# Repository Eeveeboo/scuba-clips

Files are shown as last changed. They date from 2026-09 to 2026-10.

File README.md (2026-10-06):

# Scuba Clips 🤿




Parametric (customizable) clips for scuba gear. The default parameters are for my personal kit: an [OMS Lite CB Wing BCD](https://omsdirect.com/Lite-XS-Performance-Mono-27-lbs-12.5-kg-Black/S11518023) and the [Ocea XL4 regulators](https://www.apeksdiving.com/en-us/product/xl4-ocea-stage-3-dive-regulator-octopus-726024?color=6225).

## So... what does this project generate exactly?

### Inflator Tube + SPG + LPI hose clip
I'm tiny so I can comfortably view the side of my BCD Inflator controls, so I thought "why not combine them and be more streamlined?" and that's how this whole project started 😅 This clip routes the three hoses on my left together so my SPG is on the inner "flat" face of my inflator, and currently then hair elastic'd to the side (I'll make another custom print to replace that as well soon.)

||
|-|
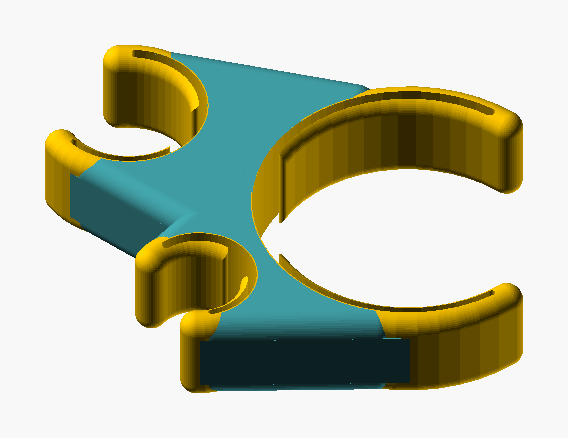
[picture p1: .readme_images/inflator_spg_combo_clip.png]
||

### Octi/Alternate clips
I just didn't like how either dangly or inaccessible all the ways I had been shown to store my alternate were (I only dive back-mount singles currently, and yes since designing these I have been told about long hose and intend to try it out soon 💖)

|Upper|Lower|
|-|-|
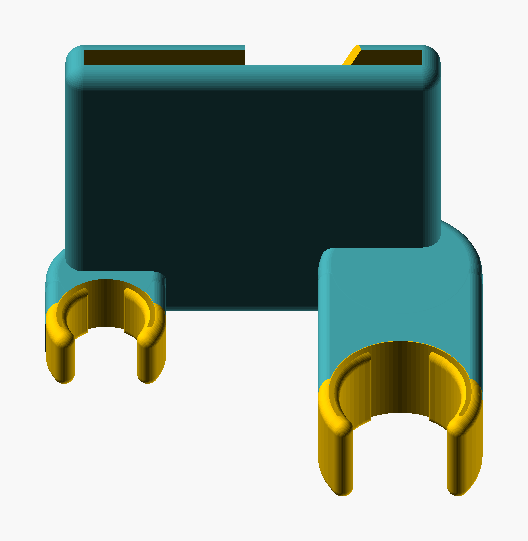
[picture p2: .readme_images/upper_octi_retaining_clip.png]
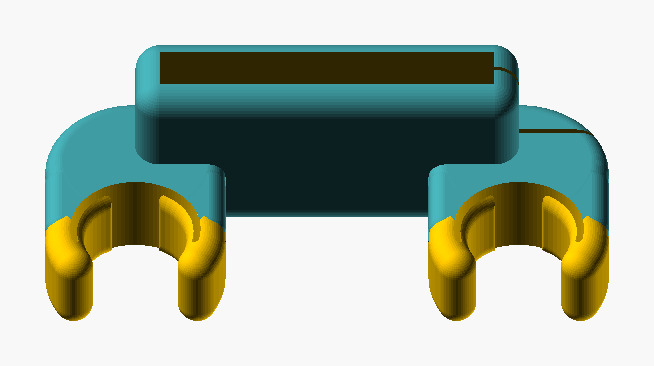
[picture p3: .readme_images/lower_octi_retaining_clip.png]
|||

### Inflator tube clip
Is this overkill to replace the velcro? Maybe, but I didn't like it, so I replaced it 🤷‍♀️ It also prevents the slippage where I feel like I always have to yank the inflator forward before descending in the velcro since it slipped back.

||
|-|
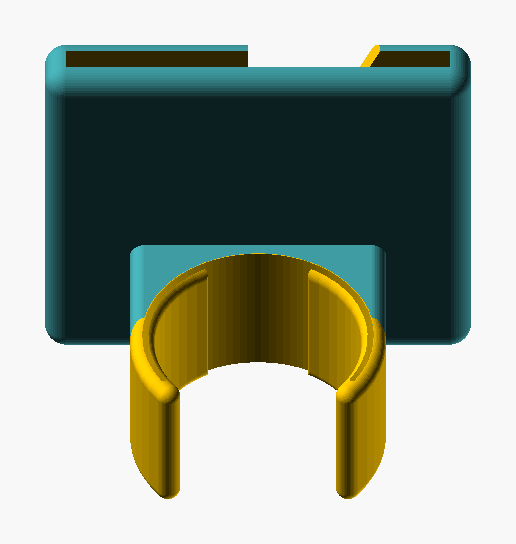
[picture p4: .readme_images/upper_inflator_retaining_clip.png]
||

### Two-way cord clip
For when two hoses only need to stay together. The two clips open away from each other (180°), and the rounded middle tapers from one hose size to the other. A small hole runs through that middle between them. A cord or a zip tie goes through the hole, so you can tie the clip to a D-ring or a bolt snap.

||
|-|
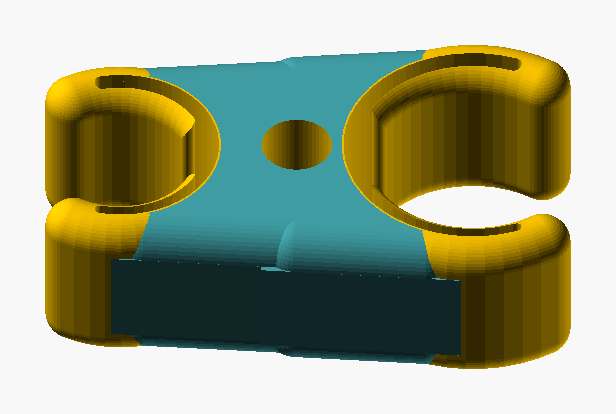
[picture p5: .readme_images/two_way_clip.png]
||

### Soft edges
Every clip has soft, rounded edges now. The rounding is not perfect: where two rounded faces meet, a small crease can remain. It is still more than good enough for a printed part, and it keeps the edges from cutting into the hose.

## So... how do I build the models myself? 🤩

### Prerequisites 🔧

* OpenSCAD 2024 or newer (nightly): <https://openscad.org/downloads.html>.
* uv: <https://docs.astral.sh/uv/getting-started/installation/>.

> ⚠️ *I've only tested this on MacOS, feel free to make a PR to fix any issues you run into 💖*

### Configuration ⚙️

Copy `config.example.toml` to `config.toml` and update the measurements to match your own kit's spacing, diameters and webbing configuration.

### Fit 🤏

The generator cuts each hose clip to the diameter you set, and it takes off no
snug allowance of its own. Set each hose diameter to the real hose size. When
you want a clip to grip the hose tighter, subtract 0.5 mm from that number.

### Generate the clips ✨

```sh
uv run cli make-all # Makes everything once
# or
uv run cli watch # Watches for file changes and rebuilds
# or
uv run flask --app main run # Starts a web server (the same one as what I host in vercel, to interactively edit the clips)
```

Once that completes you should have a bunch of files in the `build/` folder. Grab the STLs and print away! I recommend PETG + 100% infill from my testing 💖

### Troubleshooting 😭

If the generator cannot find OpenSCAD give the full path to the program:

```sh
OPENSCAD=/path/to/OpenSCAD/binary uv run cli make-all
```

## License 📜

Copyright (C) 2026 Evelyne.

This project is licensed under the [Creative Commons Attribution-NonCommercial-ShareAlike 4.0 International License](LICENSE). You may share and adapt the files, but not for commercial use, and you must give credit and share your changes under the same license.

The author keeps all rights, including the right to sell prints and files. If you want a commercial license, contact the author.

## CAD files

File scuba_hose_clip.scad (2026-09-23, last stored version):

use <roundedcube.scad>

$fn = 100;

module pie_wedge(radius, a, h = 1) {
  translate([0, 0, h / -2])
    rotate([0, 0, a / -2])
      rotate_extrude(angle=a)
        square([radius, h]);
}

module make_c_sharp(id, od, a, h) {
  difference() {
    difference() {
      cylinder(d=od, h=h, center=true);
      cylinder(d=id, h=h + 1, center=true);
    }
    pie_wedge(od, a, h + 1);
  }
}

module make_dual_c_sharp(id, od, a1, a2, h) {
  difference() {
    difference() {
      cylinder(d=od, h=h, center=true);
      cylinder(d=id, h=h + 1, center=true);
    }
    pie_wedge(od, a1, h + 1);
    rotate([0, 0, 180])
      pie_wedge(od, a2, h + 1);
  }
}

module rounded_tip(angle, radius, diameter, h) {
  rotate([0, 0, angle])
    translate([radius, 0, 0])
      cylinder(d=diameter / 2, h=h, center=true);
}

module make_c_round(id, od, a, h) {
  make_c_sharp(id, od, a, h);
  rounded_tip(a / 2, (id + od) / 4, od - id, h);
  rounded_tip(-a / 2, (id + od) / 4, od - id, h);
}

module make_dual_c_round(id, od, a1, a2, h) {
  make_dual_c_sharp(id, od, a1, a2, h);
  rounded_tip(a1 / 2, (id + od) / 4, od - id, h);
  rounded_tip(-a1 / 2, (id + od) / 4, od - id, h);
  rotate([0, 0, 180]) {
    rounded_tip(a2 / 2, (id + od) / 4, od - id, h);
    rounded_tip(-a2 / 2, (id + od) / 4, od - id, h);
  }
}

module tapered_arm(
  a_inner,
  r_inner,
  w_inner,
  a_outer,
  r_outer,
  w_outer,
  h
) {
  p1 = [r_inner * cos(a_inner), r_inner * sin(a_inner)];
  p2 = [r_outer * cos(a_outer), r_outer * sin(a_outer)];
  dir = p2 - p1;
  n = [-dir[1], dir[0]] / norm(dir); // unit perpendicular

  linear_extrude(height=h, center=true)
    polygon(
      points=[
        p1 + n * (w_inner),
        p1 + n * ( -w_inner / 4),
        p2 + n * ( -w_outer / 4),
        p2 + n * (w_outer / 4),
      ]
    );
}

module make_clip_base(
  base_diameter,
  outer_thickness,
  w_gap,
  inner_thickness,
  a_inner_back,
  a_inner_front,
  a_outer_front,
  height
) {

  // Innermost C (Canteliever)
  make_dual_c_round(
    base_diameter - inner_thickness,
    base_diameter,
    a_inner_front,
    a_inner_back,
    height
  );

  make_dual_c_round(
    base_diameter,
    base_diameter + w_gap,
    a_inner_front,
    a_inner_back,
    height
  );

  // Outer C (Structure)
  make_c_round(base_diameter + w_gap, base_diameter + w_gap + outer_thickness, a_outer_front, height);

  // Ajoining tapered arms from outer to inner
  tapered_arm(
    a_inner=a_inner_front / 2,
    r_inner=(base_diameter - inner_thickness / 2) / 2,
    w_inner=inner_thickness,
    a_outer=a_outer_front / 2,
    r_outer=(base_diameter + w_gap + outer_thickness / 2) / 2,
    w_outer=outer_thickness,
    h=height
  );

  mirror([0, 1, 0])
    tapered_arm(
      a_inner=a_inner_front / 2,
      r_inner=(base_diameter - inner_thickness / 2) / 2,
      w_inner=inner_thickness,
      a_outer=a_outer_front / 2,
      r_outer=(base_diameter + w_gap + outer_thickness / 2) / 2,
      w_outer=outer_thickness,
      h=height
    );
}

module make_scuba_clip(
  d_hose = 12,
  t_outer = 3,
  w_gap = 3,
  t_inner = 1.5,
  a_inner_back = 60,
  a_outer_front = 90,
  a_offset = 15,
  origin = "center", // center or bottom
  part = "main", // main or cutter
  h = 10
) {

  base_diameter = d_hose + t_inner / 2;
  total_diameter = base_diameter + w_gap + t_outer;
  x_offset = origin == "bottom" ? total_diameter / 2 : 0;

  module make_clip() {
    a_inner_front = a_outer_front + a_offset;

    translate([x_offset, 0, 0])
      difference() {
        make_clip_base(
          base_diameter,
          t_outer,
          w_gap,
          t_inner,
          a_inner_back,
          a_inner_front,
          a_outer_front,
          h
        );
        make_c_round(
          base_diameter,
          base_diameter + w_gap,
          a_inner_front + a_offset,
          h + 1
        );
      }
  }

  module make_reserved_clip_space() {
    translate([x_offset, 0, 0]) {
      cylinder(h=h + 1, r=total_diameter / 2, center=true);
      pie_wedge(total_diameter, a_outer_front, h + 1);
    }
  }

  if (part == "main") {
    make_clip();
  } else {
    make_reserved_clip_space();
  }
}
/*
// Print test clips to test feel
module _x(hose_diameter, t_inner, w_gap, t_outer) {
  difference() {
    translate([-9, 0, 0])
      cube([25, 12, 10], center=true);
    make_scuba_clip(
      d_hose=hose_diameter,
      t_inner=t_inner,
      w_gap=w_gap,
      t_outer=t_outer,
      origin="bottom",
      part="cutter"
    );
  }
  make_scuba_clip(
    d_hose=hose_diameter,
    t_inner=t_inner,
    w_gap=w_gap,
    t_outer=t_outer,
    origin="bottom"
  );
}

for (i = [0:3]) {
  for (j = [0:1]) {
    t_hose = i == 3 ? 27 : i + 18;
    t_outer = 3;
    t_inner = 2;
    w_gap = j + 2;
    translate([j * 40, i * 40, 0]) {
      _x(hose_diameter=t_hose, t_inner=t_inner, w_gap=w_gap, t_outer=t_outer);
      translate([1, 2.5, 4.5])
        linear_extrude(height=1) {
          text(str(t_hose, ", ", t_inner), size=5, font="Liberation Sans", halign="right", valign="center");
        }
      translate([1, -2.5, 4.5])
        linear_extrude(height=1) {
          text(str(w_gap, ", ", t_outer), size=5, font="Liberation Sans", halign="right", valign="center");
        }
    }
  }
}*/

// -- GLOBALS -- //
t_inner = 2;
t_outer = 3;
w_gap = 2;

// Used for Inflator+SPG combo clips
inflator_tube_d = 27; // Thick Inflator Tube Coming from the BCD
inflator_hose_d = 12.5; // LPI Hose from the first stage to the inflator
hp_spg_hose_d = 8; // HP Hose from the first stage to the SPG

// Used for octi organisation
reg_fitting_d = 18.5; // MP Hose fitting on the regulator
mp_reg_hose_d = 12.5; // MP Hose from the first stage to the regulator
shoulder_webbing_w = 50;
shoulder_webbing_t = 3;
hip_webbing_w = 37.5;
hip_webbing_t = 5;

module make_inflator_spg_combo_clip() {
  // Holds the three left-side suba hoses together in a nice bundle

  module _x(part, block = false) {
    union() {
      // BCD Inflator Tube
      rotate([0, 0, 180])
        make_scuba_clip(
          d_hose=inflator_tube_d,
          t_inner=t_inner,
          w_gap=w_gap,
          t_outer=t_outer,
          origin="center",
          part=part
        );

      // HP - SPG Hose
      rotate([0, 0, 30]) translate([22.5, 0, 0]) {
          rotate([0, 0, 0])
            make_scuba_clip(
              d_hose=hp_spg_hose_d,
              t_inner=t_inner,
              w_gap=w_gap,
              t_outer=t_outer,
              origin="center",
              part=part
            );
          if (block) {
            translate([-14.5, 0, 0])
              cube([29, hp_spg_hose_d + t_inner / 2 + t_outer + w_gap, 10], center=true);
          }
        }

      // LP - Inflator Hose
      rotate([0, 0, -22]) translate([30, 0, 0]) {
          rotate([0, 0, 0])
            make_scuba_clip(
              d_hose=inflator_hose_d,
              t_inner=t_inner,
              w_gap=w_gap,
              t_outer=t_outer,
              origin="center",
              part=part
            );
          if (block) {
            rotate([0, 0, -12]) translate([-14.5, 0, 0])
                cube([29, inflator_hose_d + t_inner / 2 + t_outer + w_gap, 10], center=true);
            rotate([0, 0, 12]) translate([-14.5, 0, 0])
                cube([29, inflator_hose_d + t_inner / 2 + t_outer + w_gap, 10], center=true);
          }
        }
    }
  }
  _x("main");
  difference() {
    _x("main", block=true);
    _x("cutter");
  }
}

module make_standoff_clip(h, tube_d, standoff_h) {
  rotate([0, 0, 90])
    make_scuba_clip(d_hose=tube_d, t_inner=t_inner, w_gap=w_gap, t_outer=t_outer, origin="bottom", part="main", h=h);

  d = tube_d + (w_gap + t_outer + t_inner / 2);
  difference() {
    union() {
      translate([0, -standoff_h + d / 2, h / -2]) cylinder(h=h, r=d / 2, center=false);
      translate([0, d / 2 - standoff_h / 2, 0]) cube([d, standoff_h, h], center=true);
    }

    rotate([0, 0, 90])
      make_scuba_clip(d_hose=tube_d, t_inner=t_inner, w_gap=w_gap, t_outer=t_outer, origin="bottom", part="cutter", h=h);
  }
}

module make_octi_retaining_clip_part(h, tube_d, standoff_h, w_strap, t_strap, alignment = "outer") {
  d = tube_d + (w_gap + t_outer + t_inner / 2);
  tt = t_strap + t_outer * 2;
  tw = w_strap + t_outer * 2;

  translate(alignment == "outer" ? [(tw / -2), standoff_h, 0] : [(tw / -2) - alignment, standoff_h, 0]) {
    make_standoff_clip(h, tube_d, standoff_h + tt);
  }
  translate([0, tt / -2, 0]) roundedcube(size=[tw, tt, h], center=true, radius=t_outer / 2, apply_to="all");
}
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

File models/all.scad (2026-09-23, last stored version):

// Print plate: all four models, in the layout of the old scuba_hose_clip.scad.
//
// Draft render: openscad -D MODEL_FN=36 -o out.stl models/all.scad

use <../lib/params.scad>
use <../lib/octi_clip.scad>
use <../lib/webbing_clip.scad>
use <inflator_spg_combo_clip.scad>

MODEL_FN = 100;

wall_t = 3;   // wall thickness of the webbing side clip
clip_h = 20;  // height of its webbing block
gap = 0.5;    // clearance, so the webbing slides in
tube_d = 12;  // hose held by its standoff clips

hip = webbing_hip_size();  // [width, thickness] of the hip webbing
webbing_w = hip[0];        // width along the webbing
webbing_t = hip[1];        // thickness across the webbing

inflator_spg_combo_clip(fn = MODEL_FN);
translate([100, 0, 0])
  upper_octi_clip(fn = MODEL_FN);
translate([100, -50, 0])
  lower_octi_clip(fn = MODEL_FN);
translate([0, -50, 0])
  webbing_clip(wall_t=wall_t, webbing_t=webbing_t, webbing_w=webbing_w,
               h=clip_h, gap=gap, tube_d=tube_d, fn=MODEL_FN);

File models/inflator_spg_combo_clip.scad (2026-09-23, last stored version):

// Inflator + SPG combo clip: bundles the three left-side hoses of a rig.
// Fits the 27 mm BCD inflator tube, the 12.5 mm LPI hose and the 8 mm HP/SPG
// hose.
//
// Draft render: openscad -D MODEL_FN=36 -o out.stl models/inflator_spg_combo_clip.scad

use <../lib/params.scad>
use <../lib/c_clip.scad>

MODEL_FN = 100;

// Clip walls and clip length (old file-level t_inner / t_outer / w_gap and the
// default clip height).
t_inner = 2;
t_outer = 3;
w_gap = 2;
clip_h = 10;

// Hoses this clip fits.
inflator_tube_d = hose_inflator_tube_dia();  // BCD inflator tube
lpi_hose_d = hose_lpi_dia();                 // LPI hose, first stage to inflator
hp_spg_hose_d = hose_hp_spg_dia();           // HP hose, first stage to the SPG

// Position of the HP/SPG clip around the inflator clip.
hp_spg_angle = 30;      // degrees, from the inflator clip's axis
hp_spg_radius = 22.5;   // distance from the inflator clip's centre
hp_spg_block_x = -14.5; // X centre of the block between the two clips
hp_spg_block_len = 29;  // X length of that block

// Position of the LPI clip around the inflator clip.
lpi_angle = -22;      // degrees, from the inflator clip's axis
lpi_radius = 30;      // distance from the inflator clip's centre
lpi_block_x = -14.5;  // X centre of the blocks between the two clips
lpi_block_len = 29;   // X length of those blocks
lpi_block_angle = 12; // degrees, tilt of the block on each side

module inflator_spg_combo_clip(fn = MODEL_FN) {
  $fn = fn;

  // Each hose position is written once, and both the clip and its keep-out
  // socket go through it, so the part and the cut cannot drift apart.
  module at_inflator_clip() {
    rotate([0, 0, 180]) children();
  }

  module at_hp_spg_clip() {
    rotate([0, 0, hp_spg_angle]) translate([hp_spg_radius, 0, 0]) children();
  }

  module at_lpi_clip() {
    rotate([0, 0, lpi_angle]) translate([lpi_radius, 0, 0]) children();
  }

  module bundle(blocks = false) {
    union() {
      // BCD inflator tube, clip opening away from the other two.
      at_inflator_clip()
        hose_clip(d_hose=inflator_tube_d, t_inner=t_inner, w_gap=w_gap,
                  t_outer=t_outer, h=clip_h, fn=fn);

      // HP/SPG hose.
      at_hp_spg_clip() {
        hose_clip(d_hose=hp_spg_hose_d, t_inner=t_inner, w_gap=w_gap,
                  t_outer=t_outer, h=clip_h, fn=fn);
        if (blocks)
          translate([hp_spg_block_x, 0, 0])
            cube([hp_spg_block_len,
                  clip_total_diameter(hp_spg_hose_d, t_outer, w_gap, t_inner),
                  clip_h], center=true);
      }

      // LPI hose, with a block on each side.
      at_lpi_clip() {
        hose_clip(d_hose=lpi_hose_d, t_inner=t_inner, w_gap=w_gap,
                  t_outer=t_outer, h=clip_h, fn=fn);
        if (blocks) {
          rotate([0, 0, -lpi_block_angle])
            translate([lpi_block_x, 0, 0])
              cube([lpi_block_len,
                    clip_total_diameter(lpi_hose_d, t_outer, w_gap, t_inner),
                    clip_h], center=true);
          rotate([0, 0, lpi_block_angle])
            translate([lpi_block_x, 0, 0])
              cube([lpi_block_len,
                    clip_total_diameter(lpi_hose_d, t_outer, w_gap, t_inner),
                    clip_h], center=true);
        }
      }
    }
  }

  // Keep-out volumes for the three hoses, through the same placements.
  module sockets() {
    union() {
      at_inflator_clip()
        hose_clip_socket(d_hose=inflator_tube_d, t_inner=t_inner, w_gap=w_gap,
                         t_outer=t_outer, h=clip_h, fn=fn);
      at_hp_spg_clip()
        hose_clip_socket(d_hose=hp_spg_hose_d, t_inner=t_inner, w_gap=w_gap,
                         t_outer=t_outer, h=clip_h, fn=fn);
      at_lpi_clip()
        hose_clip_socket(d_hose=lpi_hose_d, t_inner=t_inner, w_gap=w_gap,
                         t_outer=t_outer, h=clip_h, fn=fn);
    }
  }

  union() {
    bundle();
    difference() {
      bundle(blocks=true);
      sockets();
    }
  }
}

inflator_spg_combo_clip(fn = MODEL_FN);

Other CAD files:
models/lower_octi_retaining_clip.scad
dev/print_tests.scad
models/upper_octi_retaining_clip.scad
models/webbing_side_clip.scad
roundedcube.scad

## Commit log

2026-09-23 Start the scuba clips as a single OpenSCAD file.
    `scuba_hose_clip.scad` is the first working hose clip, built on `roundedcube.scad`. It is one 485-line file that mixes geometry with render calls, and the fit is still rough, but the clip prints.
    [roundedcube.scad, scuba_hose_clip.scad]
2026-09-23 Split each clip into small entry points so one change cannot move another.
    `scuba_hose_clip.scad` was one 485-line file that mixed globals, geometry, and render calls. Geometry now lives in `lib/`, each printable part is a thin file in `models/`, and `roundedcube.scad` fold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
    - 🗂️ Every part exports STLs byte-identical to the previous commit, so the split is proven, not asserted.
    - 🎲 The old code triangulated differently on repeated renders of the same input. The mesh is deterministic now, which is what makes STL diffs possible. Trade-off: the nested `for` loops in `rounded_c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
    -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
    [all.scad, inflator_spg_combo_clip.scad, lower_octi_retaining_clip.scad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]
2026-09-23 Make Python the only source for the scuba clips.
    `constants/`, `lib/`, `models/`, and `dev/` hold the builders, `tools/` renders them, and generated `.scad` is build output in `build/scad/` only. The OpenSCAD sources are gone.
    - 🐍 `make all` reproduces the four committed plates byte for byte, and `make check-baseline`, `make typecheck`, and `make lint` pass.
    - ⚠️ Two conversion-plan assumptions did not hold. `rounded_cube` keeps one `union()` per loop level so `hull()` sees the nested groups, and a nested SCAD `difference()` stays nested because solidpyt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
    [all.scad, inflator_spg_combo_clip.scad, lower_octi_retaining_clip.scad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]
2026-09-26 python migration tidy-up and better docs.
    - ⚙️ Tuning and hardware properties moved into `config.toml`
    - 🧹 The scad builder layer got a readability pass, and tessellation is a
    default now for my own sanity.
    - 📐 The standoff and joining-clip maths were reworked, and the lower
    octopus and upper inflator retaining clips were added.
    `webbing_side_clip` became `lib/webbing.py`.
    - 🎨 Coloured watch mode and a git pre-commit hook.
2026-09-26 Replace the Makefile with a Python CLI, and get the repo ready to be public. (#1)
    - 🐍 `uv run cli make-all` and friends replace the Makefile, so one tool
    runs the build instead of make plus shell.
    - 📜 Add a CC BY-NC-SA 4.0 LICENSE, and point at it from the README.
    - 🧹 Drop the make prerequisite and tidy the metadata so a new machine
    needs uv and OpenSCAD only.
2026-09-26 Pin CI actions to SHAs and add third-party notices (#4)
    - 🔒 Pin actions/checkout and astral-sh/setup-uv to full commit SHAs, and pin uv to 0.11.15.
    - 📄 Add THIRD_PARTY_NOTICES.md, with the LGPL replacement note for solidpython2.
2026-09-26 Add a hosted web editor so casual users can customize clips without downloading (#5)
    * Let a hosted editor turn clip values into OpenSCAD source
    The editor lets a casual user set the clip values and download an STL with
    no local install. The server stays cheap and stateless: it reads the field
    list from the config dataclasses and emits only the OpenSCAD text, and the
    browser makes the STL.
    - 📐 lib/config.py grows `config_schema()` and `build_config()`, and a
    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
2026-09-26 Add Web Editor and MakerWorld badges to README (#6)
    Make the live editor and the printable model easy to find from the repo.
2026-10-06 Add the two-way cord clip and finish the soft-edge pass
    - 🪢 New `two_way_clip`: two hose clips 180° apart, tapered together at the
    hub, with a cord hole through it. Config section, print plate, README and
    baseline included.
    - 🧵 The lower octi clip gets the same flared webbing slit as the upper clips
    when `tpu_mode` is on.
    - 🤏 Hose sizes now say to subtract 0.5 mm for a snug fit, and the octi clip
    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
